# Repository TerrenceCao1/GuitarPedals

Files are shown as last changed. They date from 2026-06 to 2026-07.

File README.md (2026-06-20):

# Digital Guitar Pedals

A modular digital guitar pedal platform built on the STM32F103C8T6 microcontroller. The goal is a single hardware enclosure that can be reflashed to produce different effects.

---

## Effects Firmware

| Effect | Status |
|---|---|
| Bypass (clean passthrough) | Software Tested |
| Boost | Planned |
| Overdrive / Distortion | Planned |
| Delay | Planned |
| Chorus | Planned |
| Reverb | Planned |
| Tremolo | Planned |
| Tuner | Planned |
| Looper | Planned |

---

## Hardware

### Signal Chain

```
Guitar → 1/4" input jack → input protection → op-amp buffer → ADC (PCM1802)
                                                                      ↓
Amp    ← 1/4" output jack ←   output cap    ← DAC (PCM5102A) ← STM32 via I2S
```

### Power

Powered via USB through the STM32 Blue Pill's onboard regulator. No external PSU needed.

| Rail | Source | Powers |
|---|---|---|
| 3.3V | Blue Pill `3V3` pin | STM32, PCM1802, PCM5102A |
| 5V | Blue Pill `5V` pin | MCP6002 op-amp |

### Components

| Component | Part | Status | Link |
|---|---|---|---|
| Microcontroller | STM32F103C8T6 (Blue Pill) | Have | — |
| ADC | PCM1802 | Ordered | [Amazon](https://www.amazon.com/PCM1808-Single-Ended-Analog-Input-Decoder-Amplifier/dp/B0D9LNGBD1) |
| DAC | PCM5102A breakout | Ordered | [Amazon](https://www.amazon.com/ACEIRMC-Lossless-Digital-Converter-Raspberry/dp/B08YNJGSN4) |
| Op-amp | MCP6002 (rail-to-rail, 3.3V/5V) | Ordered | [Amazon](https://www.amazon.com/MICROCHIP-MCP6002-I-OP-AMP-DIP-8-pieces/dp/B00LPJXQJW) |
| Input/output jacks | GLS 1/4" female panel jacks × 2 | Ordered | [Amazon](https://www.amazon.com/GLS-Audio-Jacks-Female-Panel/dp/B00CMXRLXM) |
| Input protection | 1MΩ resistor + 10nF capacitor | Ordered | [Resistors](https://www.amazon.com/ALLECIN-8W-Resistor-Film-Assortment/dp/B0BTP6WYH1) / [Caps](https://www.amazon.com/Multilayer-Monolithic-Capacitor-Assortment-Electronics/dp/B0D2GVNDHY) |
| Decoupling caps | 100nF ceramic × 8, 10µF electrolytic × 2 | Needed | — |
| Breadboard + jumper wires | Full-size 830-tie | Have | — |

---

## Roadmap

- [ ] Breadboard MVP — get audio passing through STM32 via I2S
- [ ] Implement and test simulations (pure software on computer)
- [ ] Test effects on firmware
- [ ] Wire potentiometers for live parameter control
- [ ] Design schematic and PCB
- [ ] Design and fabricate enclosure

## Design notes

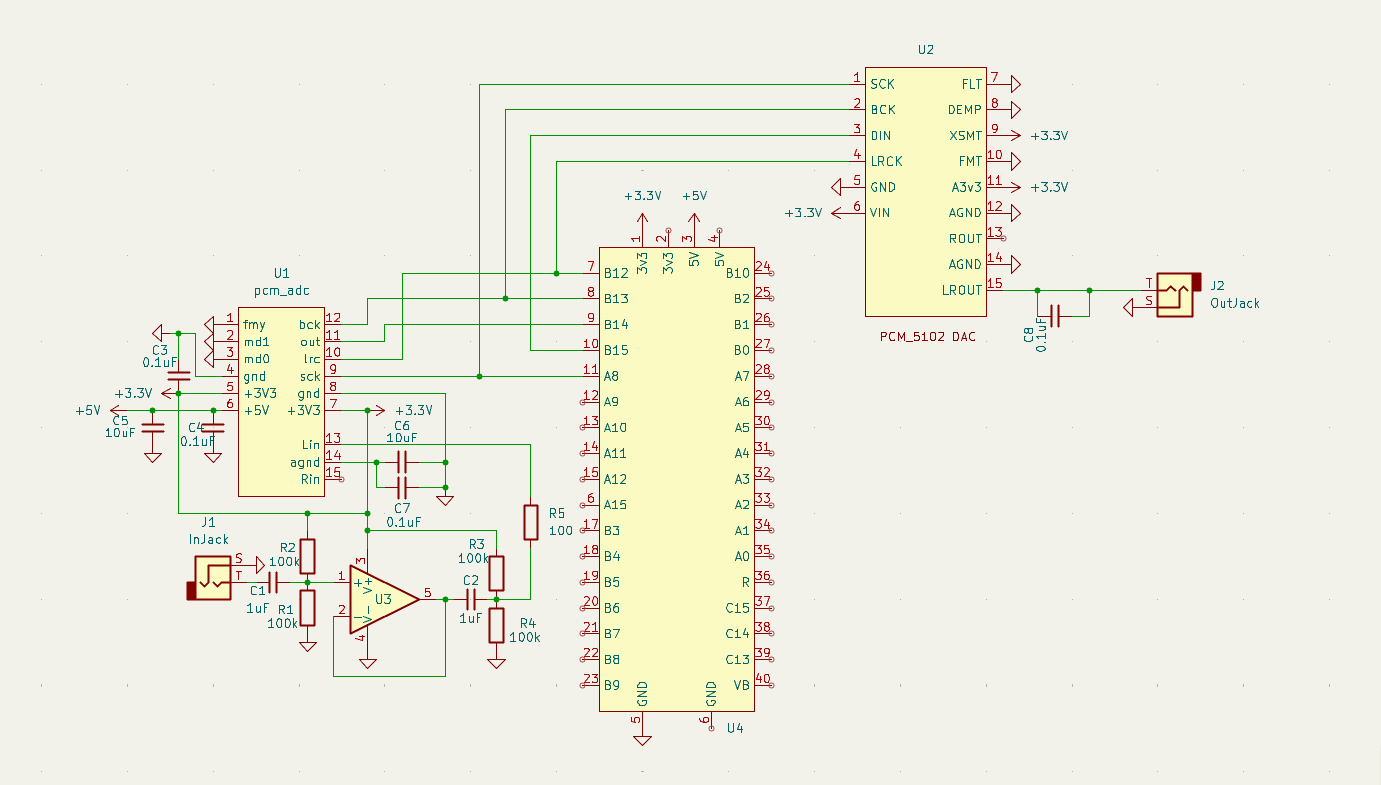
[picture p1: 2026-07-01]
doc/Schematic.png

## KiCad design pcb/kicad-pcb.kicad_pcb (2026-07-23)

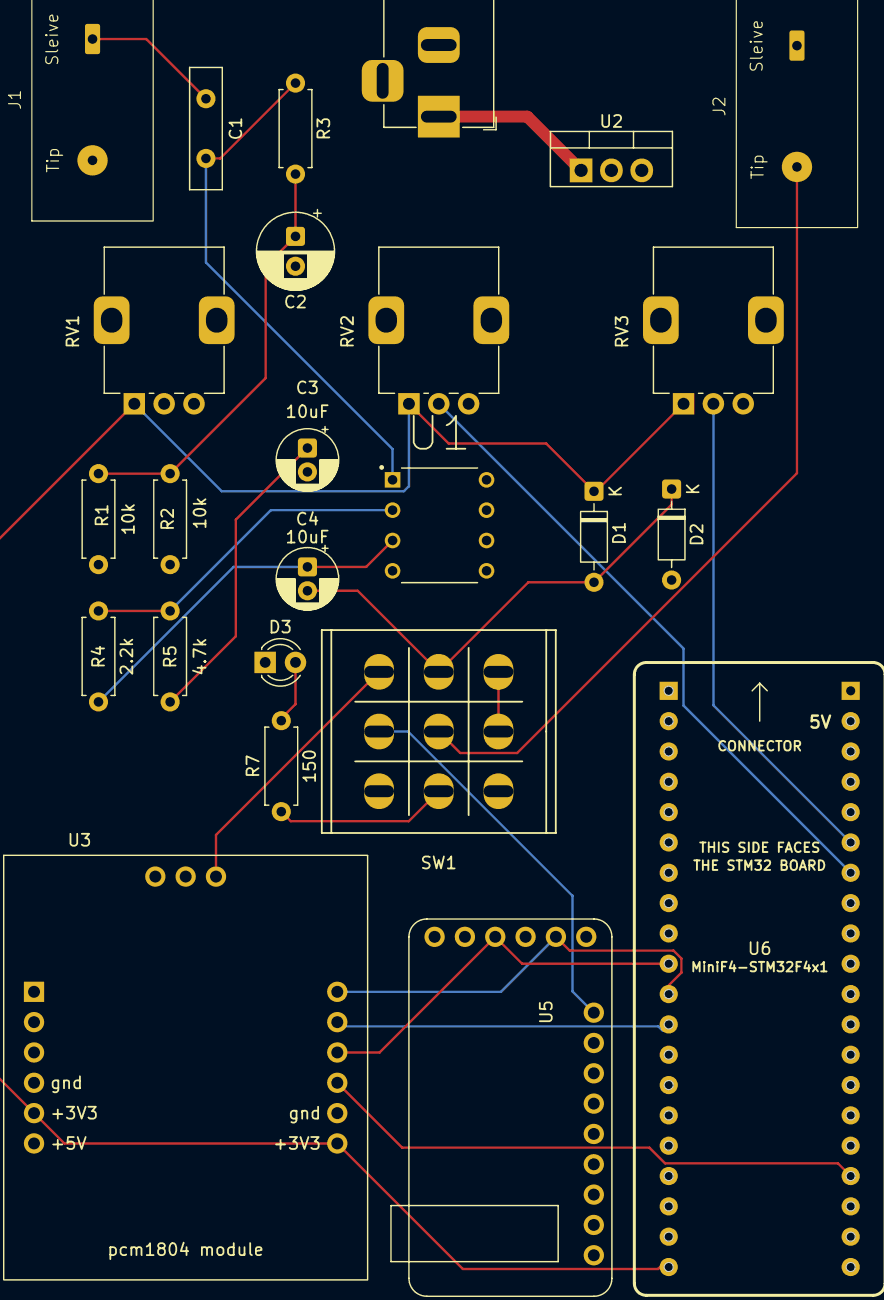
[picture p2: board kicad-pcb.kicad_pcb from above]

Board: 4 copper layers, 25 parts (0 on the bottom side), 25 nets.

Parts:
C1: 0.1uF; C_Disc_D10.0mm_W2.5mm_P5.00mm
C2: 47uF; CP_Radial_D6.3mm_P2.50mm
C3, C4: 10uF; CP_Radial_D5.0mm_P2.00mm
D1, D2: BAT41; D_DO-35_SOD27_P7.62mm_Horizontal
D3: LED; LED_D3.0mm
J1: InputJack; AudioJack
J2: OutputJack; AudioJack
J3: Power Jack; BarrelJack_Horizontal
R1, R2: 10k; R_Axial_DIN0207_L6.3mm_D2.5mm_P7.62mm_Horizontal
R3: 1M; R_Axial_DIN0207_L6.3mm_D2.5mm_P7.62mm_Horizontal
R4: 2.2k; R_Axial_DIN0207_L6.3mm_D2.5mm_P7.62mm_Horizontal
R5: 4.7k; R_Axial_DIN0207_L6.3mm_D2.5mm_P7.62mm_Horizontal
R7: 150; R_Axial_DIN0207_L6.3mm_D2.5mm_P7.62mm_Horizontal
RV1: Knob1; Potentiometer_Alps_RK09K_Single_Vertical
RV2: Knob2; Potentiometer_Alps_RK09K_Single_Vertical
RV3: Knob3; Potentiometer_Alps_RK09K_Single_Vertical
SW1: Switches_Stomp_Switch_3PDT
U1: DIP787W46P254L927H533Q8
U2: LM7805_TO220; TO-220-3_Vertical
U3: pcm_adc
U5: GY-PCM5102
U6: Mini_F4X1_STM32

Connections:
+3.3V: D1.1 (K), RV1.1, RV2.1, RV3.1, U3.8 (3.3V), U3.15 (3.3V), U6.20 (3V3), U6.23 (3V3)
+5V: R1.1, SW1.7 (A), U1.4 (V+), U2.3 (VO), U3.9 (5V), U5.6 (VIN), U6.18 (5V), U6.21 (5V)
+9V: J3.1, U2.1 (VI)
GND: C2.2, C3.2, D2.2 (A), D3.1 (K), J1.T, J2.S, J3.2, R2.2, RV1.3, RV2.3, RV3.3, SW1.9 (C), U2.2 (GND), U3.2 (GND), U3.4 (FMT), U3.5 (MD1), U3.6 (MD0), U3.7 (GND), U3.14 (GND), U5.1 (SCK), U5.5 (GND), U5.12 (G), U5.14 (G), U6.19 (GND), U6.22 (GND)
unnamed: C1.1, J1.S
unnamed: C2.1, R1.2, R2.1, R3.2
unnamed: C3.1, R5.2
unnamed: C4.1, R4.1, U1.3
unnamed: C4.2, D1.2 (A), D2.1 (K), SW1.2 (B)
unnamed: D3.2 (A), R7.2
unnamed: SW1.1 (A), U3.3 (LIN)
unnamed: SW1.3 (C), SW1.6 (C)
unnamed: SW1.4 (A), U5.15 (L)
unnamed: J2.T, SW1.5 (B)
unnamed: R7.1, SW1.8 (B)
unnamed: C1.2, R3.1, U1.1 (+)
unnamed: R4.2, R5.1, U1.2 (-)
unnamed: U3.10 (BCK), U5.2 (BCK), U6.11 (B3)
unnamed: U3.12 (LRC), U5.4 (LCK), U6.10 (A15)
unnamed: U3.11 (OUT), U6.12 (B4)
unnamed: U3.13 (SCK), U6.24 (B10)
unnamed: U5.3 (DIN), U6.13 (B5)
unnamed: RV3.2, U6.35 (A0)
unnamed: RV2.2, U6.34 (A1)
unnamed: RV1.2, U6.32 (A3)

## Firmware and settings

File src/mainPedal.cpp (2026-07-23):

// mainPedal.cpp
extern "C" {
	#include "stm32f4xx_hal.h"
	#include "stm32f4xx_hal_gpio.h"
	#include "stm32f4xx_hal_i2s.h"
	#include "stm32f4xx_hal_dma.h"
	#include "Legacy/stm32_hal_legacy.h"
	#include "stm32f411xe.h"
	#include "stm32f4xx_hal_cortex.h"
	#include "stm32f4xx_hal_def.h"
	#include "stm32f4xx_hal_i2s_ex.h"
	#include "stm32f4xx_hal_rcc.h"
	#include "main.h"
}

#include "AudioFrame.h"
#include "Effects.h"

/**I2S3 GPIO Configuration
PB3      ------> I2S3_CK
PA15     ------> I2S3_WS
PB10     ------> I2S3_MCK
PB4      ------> I2S3_ext_SD (Data In, from ADC)
PB5      ------> I2S3_SD     (Data Out, to DAC)
*/

I2S_HandleTypeDef hi2s3;
DMA_HandleTypeDef hdma_i2s3_ext_rx;
DMA_HandleTypeDef hdma_spi3_tx;

void SystemClock_Config(void);
static void MX_GPIO_Init(void);
static void MX_DMA_Init(void);
static void MX_I2S3_Init(void);
/* USER CODE BEGIN 0 */
#define AUDIO_BLOCK_SIZE	64
#define AUDIO_BUFFER_LEN	(AUDIO_BLOCK_SIZE * 2) // double buffered for ping pong

static int16_t rxBuffer[AUDIO_BUFFER_LEN];
static int16_t txBuffer[AUDIO_BUFFER_LEN];

static void ProcessBlock(int16_t* rxHalf, int16_t* txHalf, size_t blockSize = AUDIO_BLOCK_SIZE)
{
    // Simple bypass - just copy input to output
    for(size_t i = 0; i < blockSize; i++)
        txHalf[i] = rxHalf[i];
}

void HAL_I2S_RxHalfCpltCallback(I2S_HandleTypeDef* hi2s)
{
	ProcessBlock(&rxBuffer[0], &txBuffer[0], AUDIO_BLOCK_SIZE);
}

void HAL_I2S_RxCpltCallback(I2S_HandleTypeDef* hi2s)
{
	ProcessBlock(&rxBuffer[AUDIO_BLOCK_SIZE], &txBuffer[AUDIO_BLOCK_SIZE], AUDIO_BLOCK_SIZE);
}

static void BlinkN(int n)
{
    __HAL_RCC_GPIOC_CLK_ENABLE();
    GPIOC->MODER &= ~(3 << 26);
    GPIOC->MODER |= (1 << 26);
    for(int i = 0; i < n; i++)
    {
        GPIOC->BSRR = (1 << 29);  // ON
        for(volatile int d = 0; d < 2000000; d++);
        GPIOC->BSRR = (1 << 13);  // OFF
        for(volatile int d = 0; d < 2000000; d++);
    }
    // pause between groups
    for(volatile int d = 0; d < 5000000; d++);
}

/* USER CODE END 0 */

/**
	* @brief  The application entry point.
	* @retval int
	*/
int main(void)
{

	/* MCU Configuration--------------------------------------------------------*/

	/* Reset of all peripherals, Initializes the Flash interface and the Systick. */
	HAL_Init();
	/* Configure the system clock */
	MX_GPIO_Init();
	SystemClock_Config();
	/* USER CODE END SysInit */

	/* Initialize all configured peripherals */
	MX_DMA_Init();
	MX_I2S3_Init();

	/* USER CODE BEGIN 2 */
	if(HAL_I2SEx_TransmitReceive_DMA(&hi2s3, (uint16_t*)txBuffer, (uint16_t*)rxBuffer, AUDIO_BUFFER_LEN) != HAL_OK)
	{
		BlinkN(9);
		Error_Handler();
	}

	/* USER CODE END 2 */

	/* Infinite loop */
	/* USER CODE BEGIN WHILE */
	while (1)
	{
	  /* USER CODE END WHILE */

	  /* USER CODE BEGIN 3 */
	}
	/* USER CODE END 3 */
}

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


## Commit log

2026-06-25 Driver stuff
2026-06-26 initialized the GPIO's, DMA, and I2S
2026-06-26 dma interrupt boilerplate
2026-07-01 schematic + documentation
    [kicad-pcb.kicad_pcb, kicad-pcb.kicad_sch]
2026-07-01 added interupts and timer configs
2026-07-08 changed startup code and CMSIS drivers
2026-07-08 stmcubemx generated code and fixed cmake to take it
    [mainPedal.cpp]
2026-07-08 arm toolchain
2026-07-23 pcb complete
    [kicad-pcb.kicad_pcb, kicad-pcb.kicad_sch]
